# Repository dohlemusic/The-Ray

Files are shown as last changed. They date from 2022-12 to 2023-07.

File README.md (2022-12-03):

# Documentation
A detailed description of the pedal can be found on our blog at https://dohlemusic.ch/dohle-ray-from-a-boost-to-a-heavy-fuzz/

# License
The pedals are published under CC BY-NC-SA 3.0 license https://creativecommons.org/licenses/by-nc-sa/3.0/
In short, this means you can order the electronics from the schematics we publish for yourself and build them yourself, but you can't sell them and you can't publish derivatives of our works unless you mention us as the original author. If you decide to distribute your modification of our product, you can do so only under the same license, which means it can't be used for commerical purposes. We think this is fair to the users and allows them to tinker with our products, without creating a conflict of interest.

# What is the Ray?
When we designed the Ray, we wanted that huge dynamic range and detail of 12AX7 tube you can find in some Fender amps, but in a compact form factor, without building an actual tube into the pedal. We are proud to announce that we did it! We made a unique sounding pedal that offers a very similar tonal characteristics and dynamics to big tube combos, in a tiny package! Pluck the strings delicately, and you will hear the sound of your guitar, nearly unaltered, with that discrete warmth of a tube. Now pluck the strings harder and you can hear a beautiful heavy, yet detailed fuzz of a big old combo!

# What’s inside the Ray?
The pedal is fully analog and sports a subcircuit known as a Fetzer valve. Thanks to a carefully selected JFET transistor (J201) and precisely tuned biasing and capacitors, you can now enjoy a tube sound in a modern form factor. Now, the transistor alone wasn’t enough to push the pedal all the way to fuzz, so we push it with a high quality NE5532 low noise op-amp which gained quite a renown for its sound in audiophile community for its tonal properties and great sound. If you want to know more about the inner workings of this pedal, you can read our blog.

# Why the Ray?
Most fuzz or distortion pedals like the RAT rely on diodes to produce clipping, which in turn results in a very compressed sound that lacks detail and the original tone of your guitar. Ray stands out from the crowd thanks to its ability to produce a very broad dynamic range. This means that when you pluck the strings of your guitar delicately, the tone of your guitar remains almost unaltered, with a little warmth of a tube added. However, if you play the strings harder, you start hearing the warm fuzziness. Even cranked up to the maximum, the now aggressive sound produced by this pedal has very little compression and through the heavy fuzz you can still hear a lot of the original tonal value of your guitar. This is exactly what makes this pedal so unique.

# How to use the Ray
Thanks to the two knobs – V and D (Volume and Drive, respectively), you can control the op-amp gain and JFET gain individually. This means you can create a rich gamut of sounds ranging from pure undistorted boost, through pure JFET boost which has harmonic richness of a vacuum tube, or crank both knobs to the maximum and enjoy a warm fuzz of a big old combo! If you want an even heavier tone, you can toggle the presence switch for that extra fat sound!

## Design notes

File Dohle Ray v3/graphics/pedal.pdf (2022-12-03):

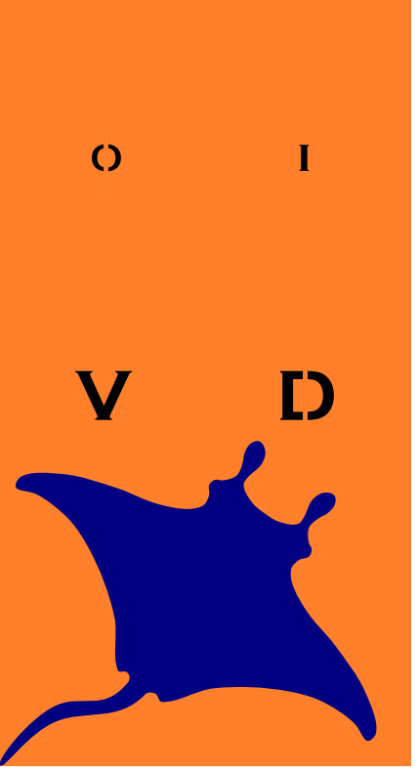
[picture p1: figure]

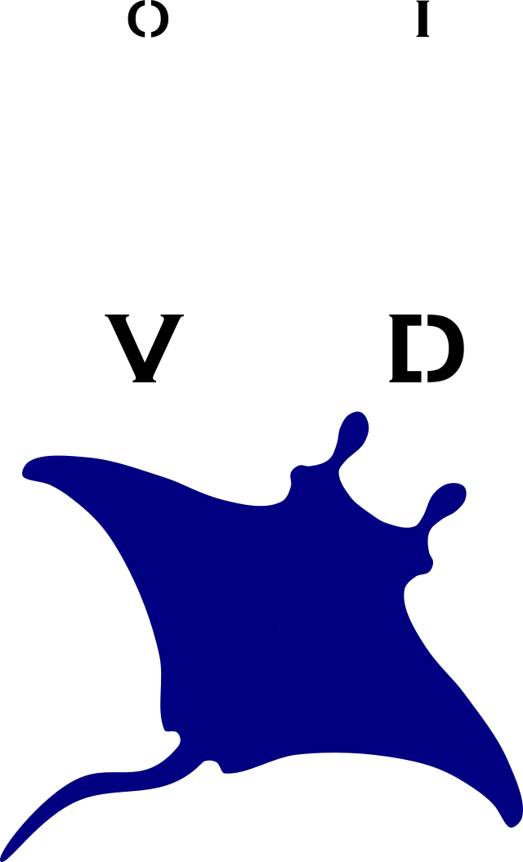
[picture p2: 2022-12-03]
Dohle Ray v3/graphics/pain_no_base_color.png

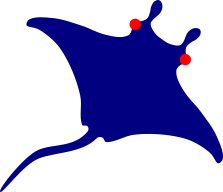
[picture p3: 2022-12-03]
Dohle Ray v3/graphics/path1213.png

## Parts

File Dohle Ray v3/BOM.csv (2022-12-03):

Source: | C:\Users\maksym\source\repos\Dohle\Dohle Ray v2\ray.kicad_sch
Date: | 18/10/2022 22:35:11
Tool: | Eeschema (6.0.0)
Generator: | C:\Program Files\KiCad\6.0\bin\scripting\plugins/bom_csv_grouped_by_value_with_fp.py
Component Count: | 33
Ref | Qnty | Value | Cmp name | Footprint | Description | Vendor
BIAS1, | 1 | 50k | R_Potentiometer_Small | Potentiometer_THT:Potentiometer_Bourns_3299W_Vertical | Potentiometer
BOOST1, | 1 | BOOST | SW_SPST | Connector_JST:JST_PH_B2B-PH-K_1x02_P2.00mm_Vertical | Single Pole Single Throw (SPST) switch
C1, C5, | 2 | 100n | C_Small | Capacitor_THT:C_Rect_L7.0mm_W4.5mm_P5.00mm | Unpolarized capacitor, small symbol
C2, C4, | 2 | 220n | C_Small | Capacitor_THT:C_Rect_L7.0mm_W4.5mm_P5.00mm | Unpolarized capacitor, small symbol
C3, | 1 | 47u | C_Polarized_Small | Capacitor_THT:CP_Radial_D5.0mm_P2.00mm | Polarized capacitor, small symbol
C6, | 1 | 220p | C_Small | Capacitor_THT:C_Rect_L7.0mm_W2.0mm_P5.00mm | Unpolarized capacitor, small symbol
C7, | 1 | 47n | C_Small | Capacitor_THT:C_Disc_D5.0mm_W2.5mm_P5.00mm | Unpolarized capacitor, small symbol
C8, | 1 | 22u | C_Polarized_Small | Capacitor_THT:CP_Radial_D5.0mm_P2.50mm | Polarized capacitor, small symbol
D1, | 1 | BZX55C4V7 | D_Zener | Diode_THT:D_DO-35_SOD27_P7.62mm_Horizontal | Zener diode
D2, | 1 | 1n4001 | 1N4148 | Diode_THT:D_DO-15_P12.70mm_Horizontal | 100V 0.15A standard switching diode, DO-35
DRV1, | 1 | 500kLin | R_Potentiometer_Small | Connector_JST:JST_PH_B3B-PH-K_1x03_P2.00mm_Vertical | Potentiometer
EYES1, | 1 | 15mA | LED | Connector_JST:JST_PH_B2B-PH-K_1x02_P2.00mm_Vertical | Light emitting diode
F1, | 1 | <200mA PTC | Fuse | Capacitor_THT:C_Rect_L7.0mm_W4.5mm_P5.00mm | Fuse
GAIN1, | 1 | 500k Log | R_Potentiometer_Small | Connector_JST:JST_PH_B3B-PH-K_1x03_P2.00mm_Vertical | Potentiometer
IN1, | 1 | In | Conn_01x02_Female | Connector_JST:JST_PH_B2B-PH-K_1x02_P2.00mm_Vertical | Generic connector, single row, 01x02, script generated (kicad-library-utils/schlib/autogen/connector/)
OUT1, | 1 | Out | Conn_01x02_Female | Connector_JST:JST_PH_B2B-PH-K_1x02_P2.00mm_Vertical | Generic connector, single row, 01x02, script generated (kicad-library-utils/schlib/autogen/connector/)
PWR1, | 1 | 9V | Conn_01x02_Female | Connector_JST:JST_PH_B2B-PH-K_1x02_P2.00mm_Vertical | Generic connector, single row, 01x02, script generated (kicad-library-utils/schlib/autogen/connector/)
Q1, | 1 | J201 | Q_NJFET_DSG | Package_TO_SOT_SMD:SOT-23_Handsoldering | N-JFET transistor, drain/source/gate
R1, R8, | 2 | 1k | R_Small | Resistor_THT:R_Axial_DIN0207_L6.3mm_D2.5mm_P10.16mm_Horizontal | Resistor, small symbol
R2, R3, R10, | 3 | 10k | R_Small | Resistor_THT:R_Axial_DIN0207_L6.3mm_D2.5mm_P10.16mm_Horizontal | Resistor, small symbol
R4, | 1 | 47k | R_Small | Resistor_THT:R_Axial_DIN0207_L6.3mm_D2.5mm_P10.16mm_Horizontal | Resistor, small symbol
R5, R7, | 2 | 24k | R_Small | Resistor_THT:R_Axial_DIN0207_L6.3mm_D2.5mm_P10.16mm_Horizontal | Resistor, small symbol
R6, | 1 | 470 | R_Small | Resistor_THT:R_Axial_DIN0207_L6.3mm_D2.5mm_P10.16mm_Horizontal | Resistor, small symbol
R9, | 1 | 100k | R_Small | Resistor_THT:R_Axial_DIN0207_L6.3mm_D2.5mm_P10.16mm_Horizontal | Resistor, small symbol
SW1, | 1 | 3pdt_footswitch | 3pdt_footswitch | footprints:3pdt_footswitch
TP1, | 1 | VBias | MountingHole_Pad | TestPoint:TestPoint_THTPad_1.5x1.5mm_Drill0.7mm | Mounting Hole with connection
U1, | 1 | TL082 | TL082 | Package_DIP:DIP-8_W7.62mm_Socket_LongPads | Dual JFET-Input Operational Amplifiers, DIP-8/SOIC-8/SSOP-8

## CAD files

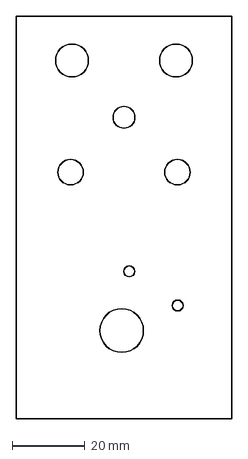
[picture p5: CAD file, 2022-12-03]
Dohle Ray v3/graphics/holes.dxf
59.3 x 110.7 mm

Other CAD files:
Dohle Ray v3/IO Board/IO Board-B_Silkscreen.dxf
Dohle Ray v3/IO Board/IO Board-F_Silkscreen.dxf

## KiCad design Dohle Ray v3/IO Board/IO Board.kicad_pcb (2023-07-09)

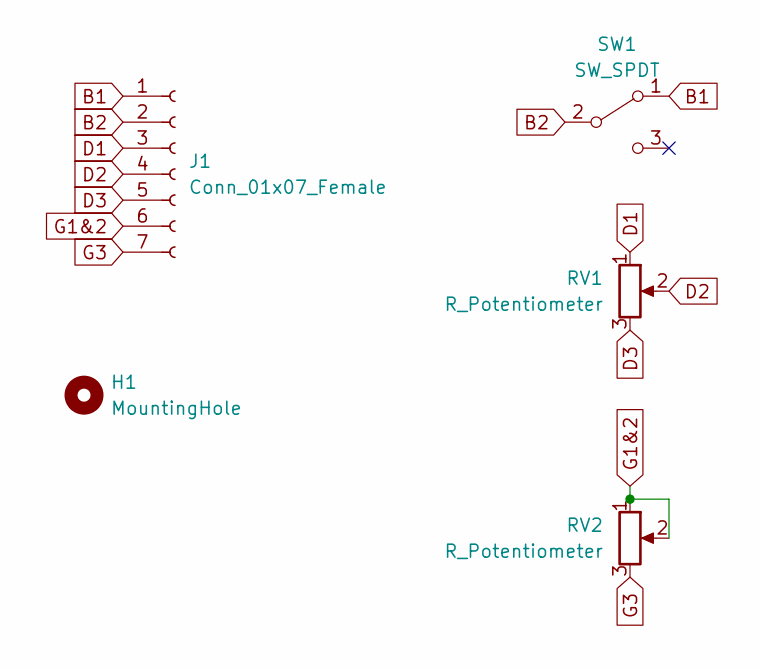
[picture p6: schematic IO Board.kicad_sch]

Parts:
H1: MountingHole; MountingHole_2.2mm_M2
J1: Conn_01x07_Female; PinHeader_1x07_P2.54mm_Vertical
RV1, RV2: R_Potentiometer; Vertical big potentiometer
SW1: SW_SPDT; SPDT_fi6mm_footswitch

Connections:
B1: J1.1, SW1.1 (A)
B2: J1.2, SW1.2 (B)
D1: J1.3, RV1.1
D2: J1.4, RV1.2
D3: J1.5, RV1.3
G1&2: J1.6, RV2.1, RV2.2
G3: J1.7, RV2.3

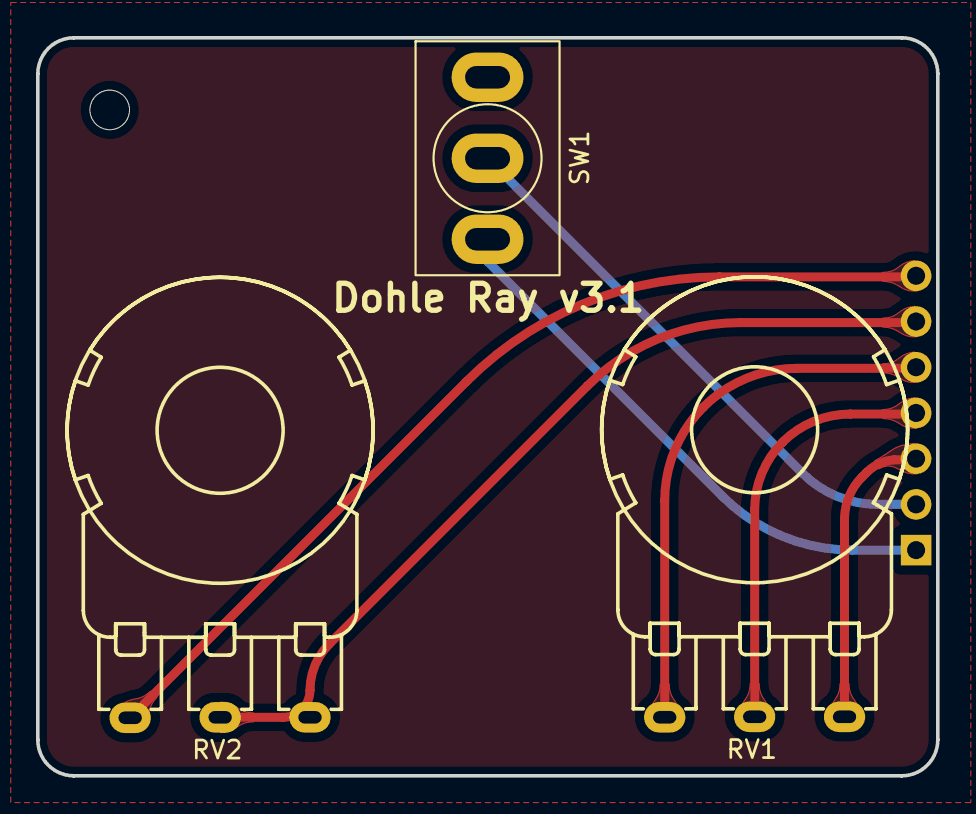
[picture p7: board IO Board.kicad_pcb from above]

Board: 2 copper layers, 50.0 x 41.0 mm, 5 parts (1 on the bottom side), 7 nets.

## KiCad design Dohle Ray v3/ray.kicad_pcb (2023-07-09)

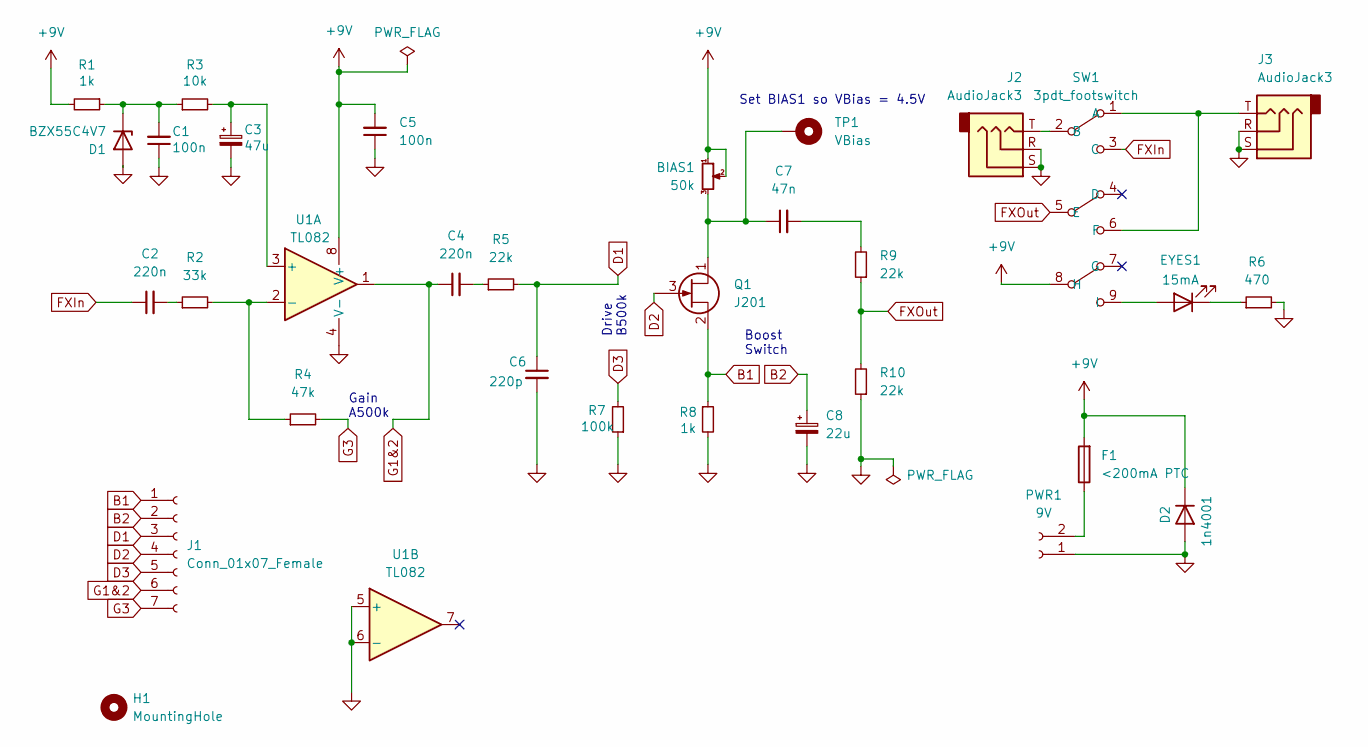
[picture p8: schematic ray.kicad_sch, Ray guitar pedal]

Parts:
BIAS1: 50k; Potentiometer_Bourns_3299W_Vertical
C1, C5: 100n; C_Rect_L7.0mm_W4.5mm_P5.00mm
C2, C4: 220n; C_Rect_L7.0mm_W4.5mm_P5.00mm
C3: 47u; CP_Radial_D5.0mm_P2.50mm
C6: 220p; C_Rect_L7.0mm_W2.0mm_P5.00mm
C7: 47n; C_Disc_D5.0mm_W2.5mm_P5.00mm
C8: 22u; CP_Radial_D5.0mm_P2.50mm
D1: BZX55C4V7; D_DO-35_SOD27_P7.62mm_Horizontal
D2: 1n4001; D_DO-15_P12.70mm_Horizontal
EYES1: 15mA; JST_PH_B2B-PH-K_1x02_P2.00mm_Vertical
F1: <200mA PTC; C_Rect_L7.0mm_W4.5mm_P5.00mm
H1: MountingHole; MountingHole_2.2mm_M2
J1: Conn_01x07_Female; PinSocket_1x07_P2.54mm_Vertical
J2, J3: AudioJack3; StereoJackVertical
PWR1: 9V; JST_PH_B2B-PH-K_1x02_P2.00mm_Vertical
Q1: J201; SOT-23_Handsoldering
R1, R8: 1k; R_Axial_DIN0207_L6.3mm_D2.5mm_P10.16mm_Horizontal
R2: 33k; R_Axial_DIN0207_L6.3mm_D2.5mm_P10.16mm_Horizontal
R3: 10k; R_Axial_DIN0207_L6.3mm_D2.5mm_P10.16mm_Horizontal
R4: 47k; R_Axial_DIN0207_L6.3mm_D2.5mm_P10.16mm_Horizontal
R5, R9, R10: 22k; R_Axial_DIN0207_L6.3mm_D2.5mm_P10.16mm_Horizontal
R6: 470; R_Axial_DIN0207_L6.3mm_D2.5mm_P10.16mm_Horizontal
R7: 100k; R_Axial_DIN0207_L6.3mm_D2.5mm_P10.16mm_Horizontal
SW1: 3pdt_footswitch
TP1: VBias; TestPoint_THTPad_1.5x1.5mm_Drill0.7mm
U1: TL082; DIP-8_W7.62mm_Socket_LongPads

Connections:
+9V: BIAS1.1, BIAS1.2, C5.2, D2.1 (K), F1.2, R1.2, SW1.8 (H), U1.8 (V+)
B1: J1.1, Q1.2 (S), R8.1
B2: C8.1, J1.2
D1: C6.1, J1.3, R5.2
D2: J1.4, Q1.3 (G)
D3: J1.5, R7.2
FXIn: C2.1, SW1.3 (C)
FXOut: R9.1, R10.2, SW1.5 (E)
G1&2: C4.1, J1.6, U1.1
G3: J1.7, R4.2
GND: C1.1, C3.2, C5.1, C6.2, C8.2, D1.2 (A), D2.2 (A), J2.R, J2.S, J3.R, J3.S, PWR1.1, R6.2, R7.1, R8.2, R10.1, U1.4 (V-), U1.5 (+), U1.6 (-)
unnamed: BIAS1.3, C7.1, Q1.1 (D), TP1.1
unnamed: C1.2, D1.1 (K), R1.1, R3.1
unnamed: C2.2, R2.1
unnamed: C3.1, R3.2, U1.3 (+)
unnamed: C4.2, R5.1
unnamed: C7.2, R9.2
unnamed: EYES1.1 (K), R6.1
unnamed: EYES1.2 (A), SW1.9 (I)
unnamed: F1.1, PWR1.2
unnamed: J2.T, SW1.2 (B)
unnamed: J3.T, SW1.1 (A), SW1.6 (F)
unnamed: R2.2, R4.1, U1.2 (-)

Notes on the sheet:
Boost Switch
Drive B500k
Set BIAS1 so VBias = 4.5V
Gain A500k

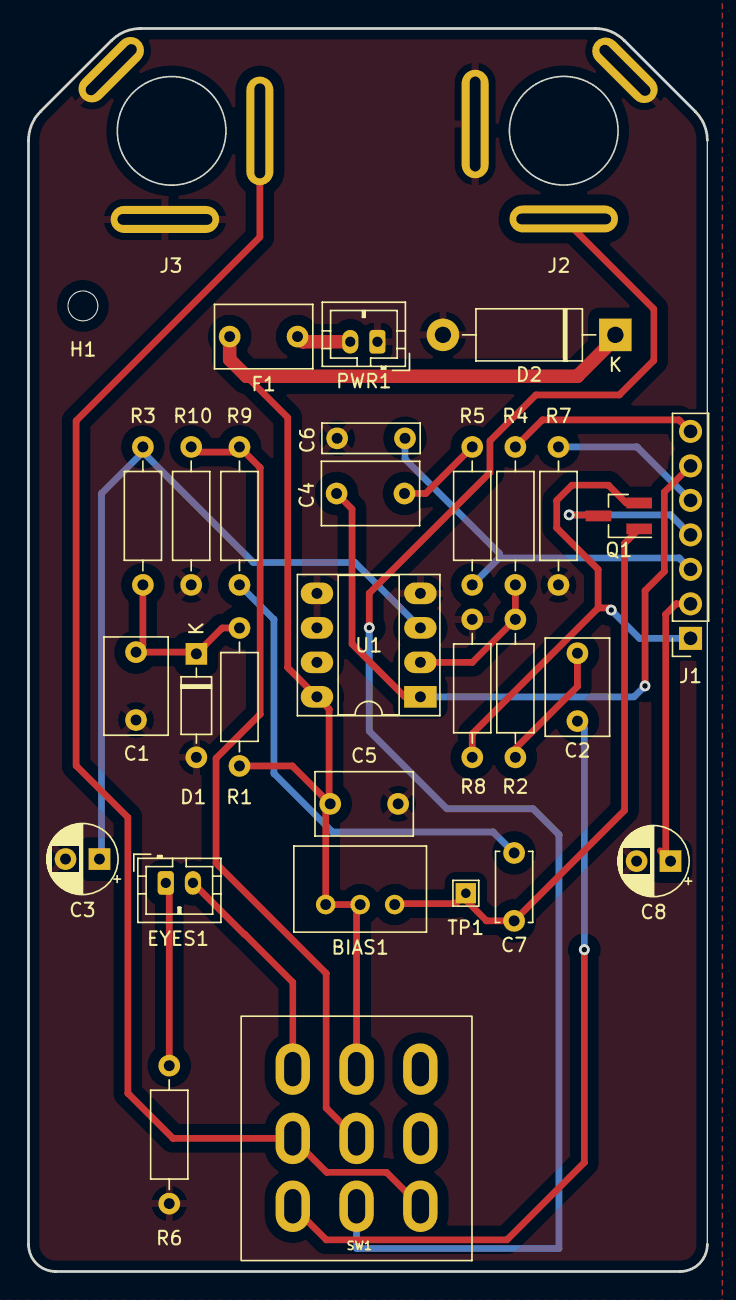
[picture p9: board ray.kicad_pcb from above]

Board: 2 copper layers, 50.0 x 91.6 mm, 32 parts (0 on the bottom side), 23 nets.

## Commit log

2022-12-03 Add ray pedals
    [IO Board-B_Silkscreen.dxf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]
2022-12-03 Update version and fix faulty jack wiring
    [ray-rounded.kicad_pcb, ray.kicad_pcb]
2022-12-03 Export to jlcpcb
    [BOM.csv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]
2022-12-12 Prepare fabrication data
    [ray-rounded-B_Cu.gbl, ray-rounded-B_Mask.gbs, ray-rounded-B_Paste.gbp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]
2023-06-22 Update resistor values
    [ray.kicad_sch]
2023-07-09 Update resistor values to have unity gain at 0% volume and gain knob, update PCB revision
    [IO Board-B_Cu.gbl, IO Board-B_Mask.gbs, IO Board-B_Paste.gbp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]
